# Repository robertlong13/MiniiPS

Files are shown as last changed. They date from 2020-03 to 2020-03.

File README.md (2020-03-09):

# MiniiPS
Custom regulator board for miniaturized Wii. Provides 1V, 1.15V, 3.3V, 5V. Similar to the PowerMiiLite, but larger and a few extra features specific to my personal project. Should be good for any wall-powered mini Wii project.

### Goals for this power supply
* Be small. Can't really afford much more space than 20mm by 60mm
* Use a 5V 3A USB-C charger for input power
* Have an enable pin for turning on and off the power supply. The slide switch I'm using for power is only rated for 200mA.
* Design the 3.3V, 1.15V, and 1V regulators for 3A output, and 15V input voltage. I'm over-engineering to give myself maximum chance of getting it right on the first try, instead of pushing all my components right to their spec. There could be some reason I this is a bad idea, but I can't think of one.
* Be easy to hand assemble (using skillet reflow) and rework. An automated assembly run is out of the question. Smallest passives are 0603 (1608 metric).

To power on the outputs, the enable pad must be pulled high with your power switch. By default, that pad is pulled low with a 10K resistor.

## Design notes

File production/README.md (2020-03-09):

# Production
This folder contains all necessary for manufacturing

|File Name| Description  |
|--|--|
| BOM.csv | Bill of Materials, CSV |
| BOM.xlsx | Bill of Materials, Excel |
| ComponentPlacement.pdf | Reference for Hand Assembly |
| MiniiPS-B_Cu.gbr | Bottom Copper |
| MiniiPS-B_Mask.gbr | Bottom Soldermask |
| MiniiPS-B_Paste.gbr | Bottom Solderpaste |
| MiniiPS-B_SilkS.gbr | Bottom Silkscreen |
| MiniiPS-Edge_Cuts.gbr | Board Outline |
| MiniiPS-F_Cu.gbr | Top Copper |
| MiniiPS-F_Mask.gbr | Top Soldermask |
| MiniiPS-F_Paste.gbr | Top Solderpaste |
| MiniiPS-F_SilkS.gbr | Top Silkscreen |
| MiniiPS-PTH.drl | Plated Holes |

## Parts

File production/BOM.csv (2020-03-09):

Reference(s) | Value | MFG Name | MFG Part Num | Description | Qty
C1, C2, C8, C9, C15, C16 | 10u | Taiyo Yuden | TMK212BBJ106KG-T | CAP CER 10UF 25V X5R 0805 | 6
C3, C4, C10, C11, C17, C18, C23, C24 | 100n | Samsung Electro-Mechanics | CL10B104KB8NNNC | CAP CER 0.1UF 50V X7R 0603 | 8
C5, C6, C7, C12, C13, C14, C19, C20, C21, C22, C25 | 22u | Samsung Electro-Mechanics | CL21A226MQQNNNE | CAP CER 22UF 6.3V X5R 0805 | 11
J1 |  | GCT | USB4085-GF-A | CONN RCPT USB2.0 TYPEC 16POS | 1
L1, L2, L3 | 2u2 | Murata Electronics | 1264EY-2R2N=P3 | FIXED IND 2.2UH 7.8A 19.2 MOHM | 3
R1 | 3K16 | Stackpole Electronics Inc | RMCF0603FT3K16 | RES 3.16K OHM 1% 1/10W 0603 | 1
R2, R4, R6, R7, R8 | 10K | Stackpole Electronics Inc | RMCF0603FT10K0 | RES 10K OHM 1% 1/10W 0603 | 5
R3, R9, R10 | 5K11 | Stackpole Electronics Inc | RMCF0603FT5K11 | RES 5.11K OHM 1% 1/10W 0603 | 3
R5 | 33K2 | Stackpole Electronics Inc | RMCF0603FT33K2 | RES 33.2K OHM 1% 1/10W 0603 | 1
U1, U2, U3 | TPS564201 | Texas Instruments | TPS564201DDCR | IC REG BUCK ADJ 4A TSOT23-6 | 3
U4 | AP2171 | Diodes Incorporated | AP2171WG-7 | IC PWR SWITCH P-CHAN 1:1 SOT25 | 1

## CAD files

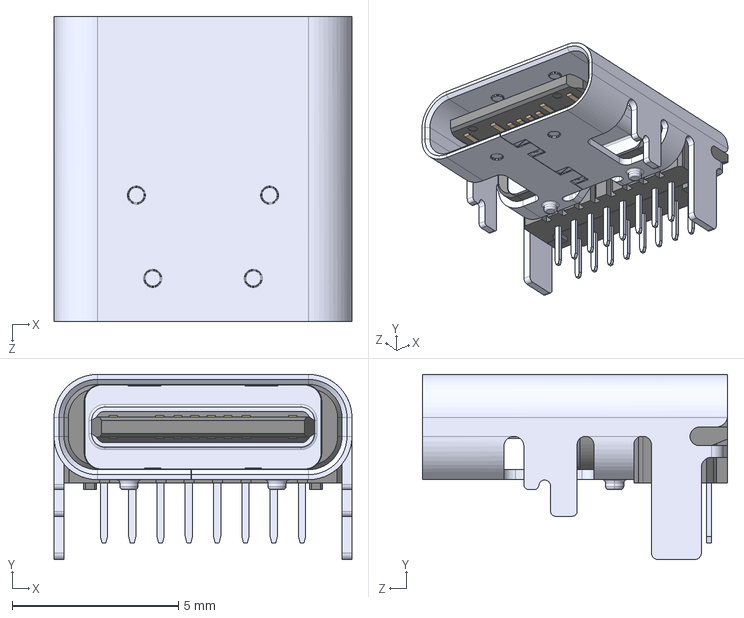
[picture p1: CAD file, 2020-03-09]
USB4085-GF-A--3DModel-STEP-56544.STEP
8.95 x 5.56 x 9.17 mm

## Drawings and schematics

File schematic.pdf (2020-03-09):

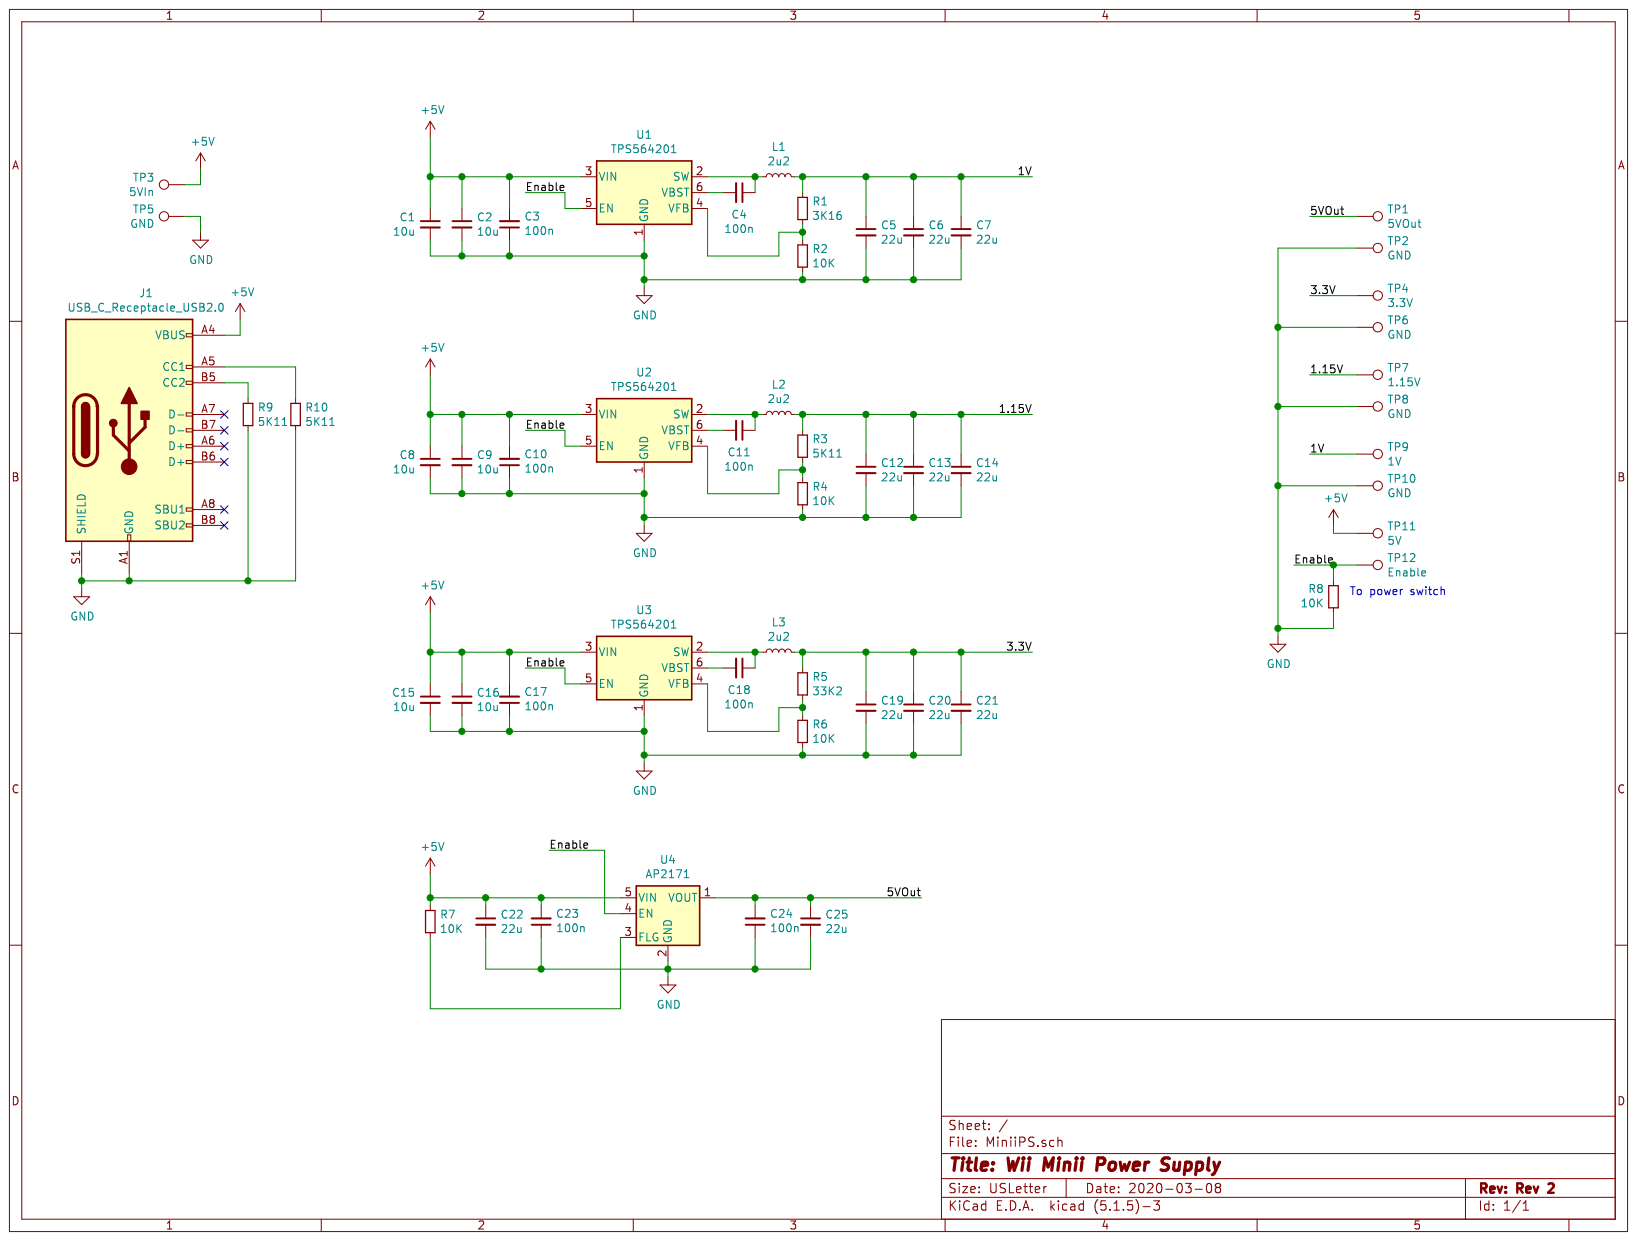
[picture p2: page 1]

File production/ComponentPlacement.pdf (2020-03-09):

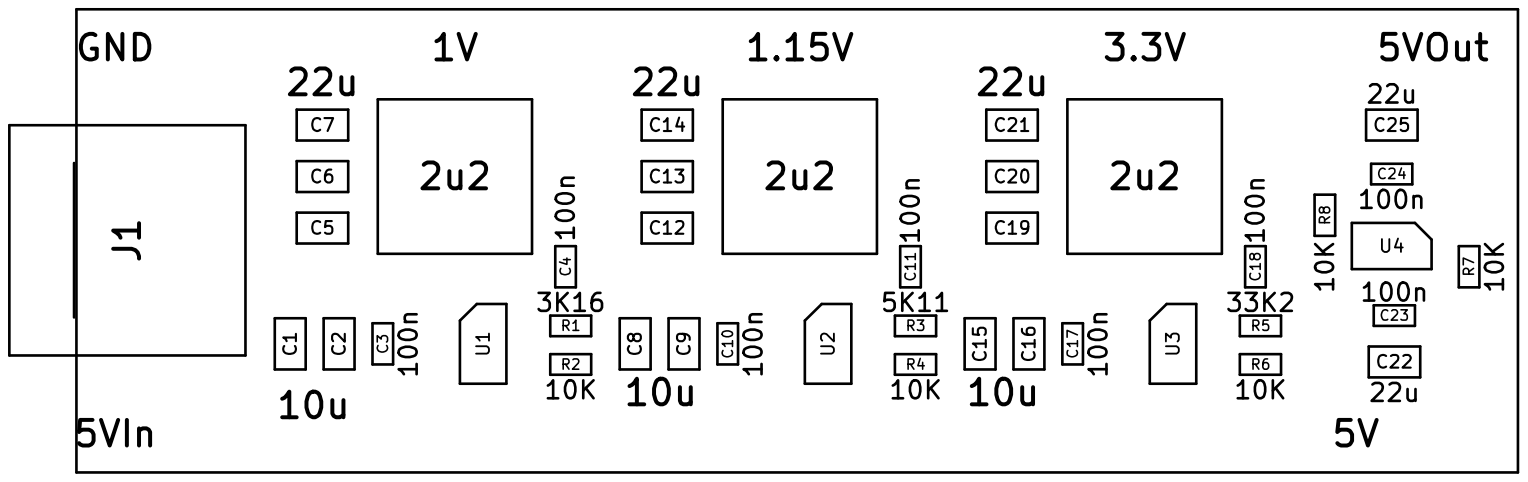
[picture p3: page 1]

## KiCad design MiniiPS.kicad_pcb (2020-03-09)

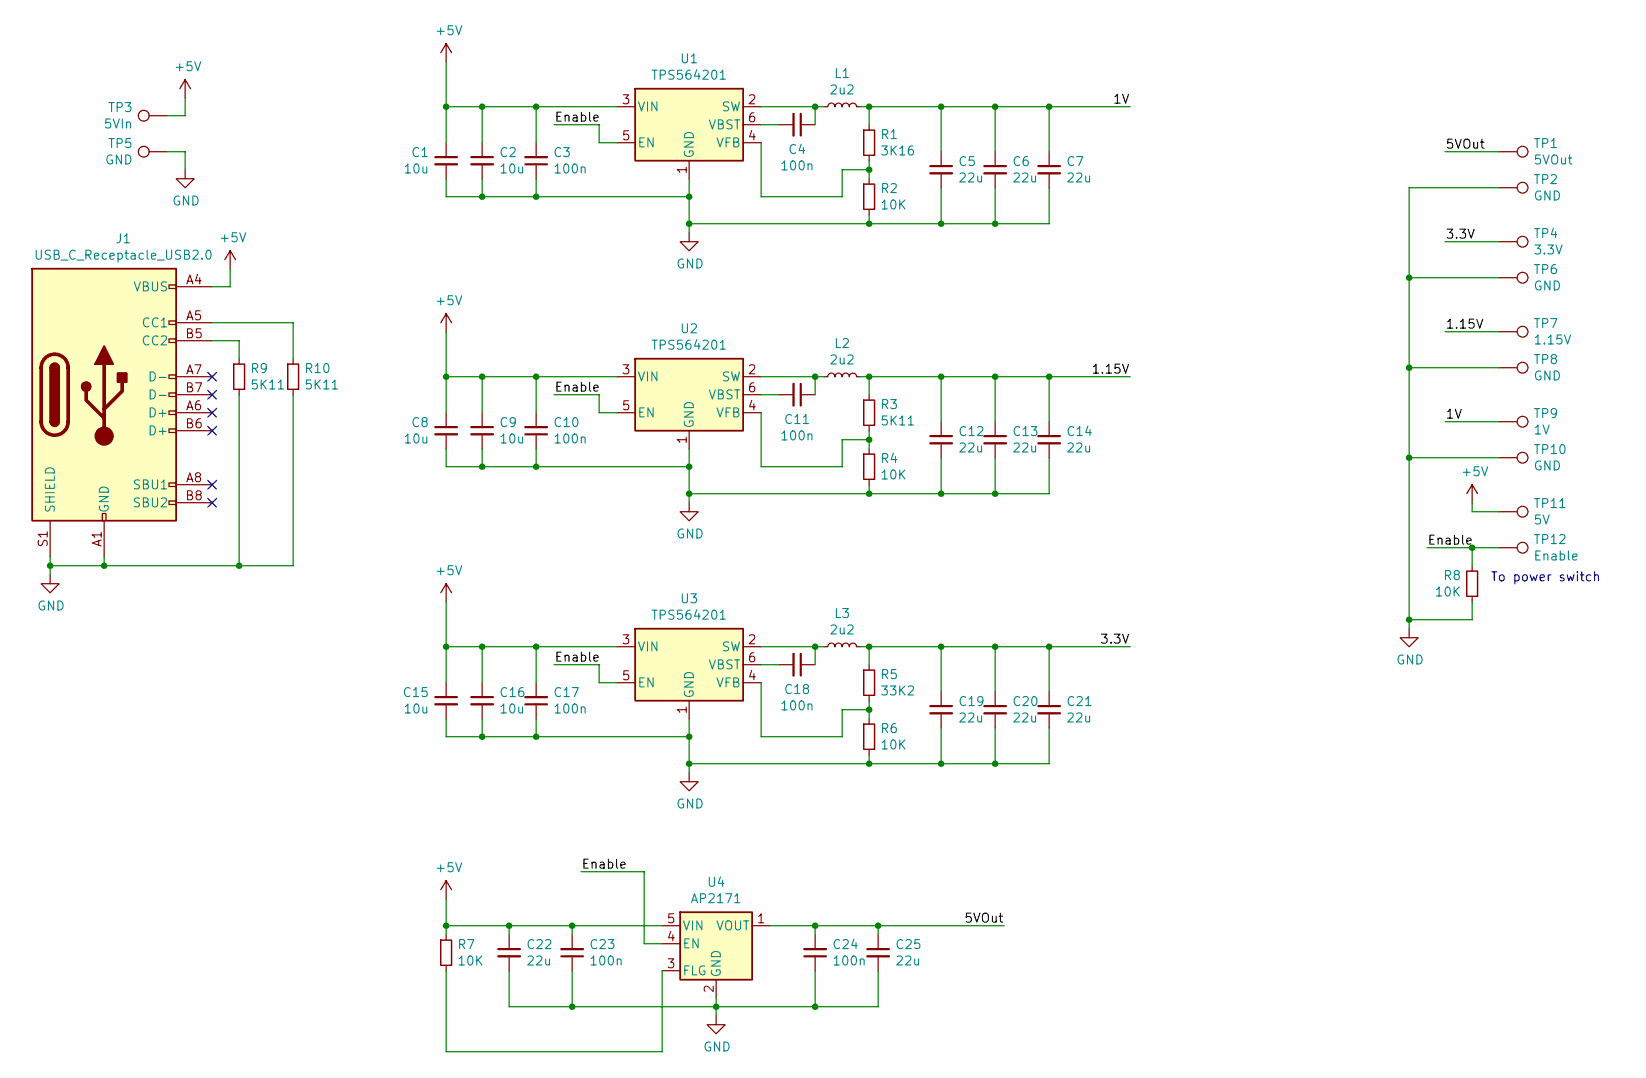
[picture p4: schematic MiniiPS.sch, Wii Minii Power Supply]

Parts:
C1, C2, C8, C9, C15, C16: 10u; C_0805_2012Metric; MFG Part Num TMK212BBJ106KG-T
C3, C4, C10, C11, C17, C18, C23, C24: 100n; C_0603_1608Metric; MFG Part Num CL10B104KB8NNNC
C5, C6, C7, C12, C13, C14, C19, C20, C21, C22, C25: 22u; C_0805_2012Metric; MFG Part Num CL21A226MQQNNNE
J1: USB_C_Receptacle_USB2.0; USB_C_Receptacle_GCT_USB4085; MFG Part Num USB4085-GF-A
L1, L2, L3: 2u2; MFG Part Num 1264EY-2R2N=P3
R1: 3K16; R_0603_1608Metric; MFG Part Num RMCF0603FT3K16
R2, R4, R6, R7, R8: 10K; R_0603_1608Metric; MFG Part Num RMCF0603FT10K0
R3, R9, R10: 5K11; R_0603_1608Metric; MFG Part Num RMCF0603FT5K11
R5: 33K2; R_0603_1608Metric; MFG Part Num RMCF0603FT33K2
TP1: 5VOut; TestPoint_Pad_4.0x4.0mm
TP2, TP5, TP6, TP8, TP10: GND; TestPoint_Pad_4.0x4.0mm
TP3: 5VIn; TestPoint_Pad_4.0x4.0mm
TP4: 3.3V; TestPoint_Pad_4.0x4.0mm
TP7: 1.15V; TestPoint_Pad_4.0x4.0mm
TP9: 1V; TestPoint_Pad_4.0x4.0mm
TP11: 5V; TestPoint_Pad_4.0x4.0mm
TP12: Enable; TestPoint_Pad_4.0x4.0mm
U1, U2, U3: TPS564201; SOT-23-6; MFG Part Num TPS564201DDCR
U4: AP2171; SOT-23-5; MFG Part Num AP2171WG-7

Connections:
+5V: C1.1, C2.1, C3.2, C8.1, C9.1, C10.2, C15.1, C16.1, C17.2, C22.1, C23.2, J1.A4 (VBUS), J1.A9 (VBUS), J1.B4 (VBUS), J1.B9 (VBUS), R7.1, TP3.1, TP11.1, U1.3 (VIN), U2.3 (VIN), U3.3 (VIN), U4.5 (VIN)
/1.15V: C12.1, C13.1, C14.1, L2.2, R3.1, TP7.1
/1V: C5.1, C6.1, C7.1, L1.2, R1.1, TP9.1
/3.3V: C19.1, C20.1, C21.1, L3.2, R5.1, TP4.1
/5VOut: C24.2, C25.1, TP1.1, U4.1 (VOUT)
/Enable: R8.2, TP12.1, U1.5 (EN), U2.5 (EN), U3.5 (EN), U4.4 (EN)
GND: C1.2, C2.2, C3.1, C5.2, C6.2, C7.2, C8.2, C9.2, C10.1, C12.2, C13.2, C14.2, C15.2, C16.2, C17.1, C19.2, C20.2, C21.2, C22.2, C23.1, C24.1, C25.2, J1.A1 (GND), J1.A12 (GND), J1.B1 (GND), J1.B12 (GND), J1.S1 (SHIELD), R2.2, R4.2, R6.2, R8.1, R9.2, R10.2, TP2.1, TP5.1, TP6.1, TP8.1, TP10.1, U1.1 (GND), U2.1 (GND), U3.1 (GND), U4.2 (GND)
unnamed: C4.1, L1.1, U1.2 (SW)
unnamed: C4.2, U1.6 (VBST)
unnamed: C11.1, L2.1, U2.2 (SW)
unnamed: C11.2, U2.6 (VBST)
unnamed: C18.1, L3.1, U3.2 (SW)
unnamed: C18.2, U3.6 (VBST)
unnamed: J1.A5 (CC1), R10.1
unnamed: J1.B5 (CC2), R9.1
unnamed: R1.2, R2.1, U1.4 (VFB)
unnamed: R3.2, R4.1, U2.4 (VFB)
unnamed: R5.2, R6.1, U3.4 (VFB)
unnamed: R7.2, U4.3 (FLG)

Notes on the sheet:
To power switch

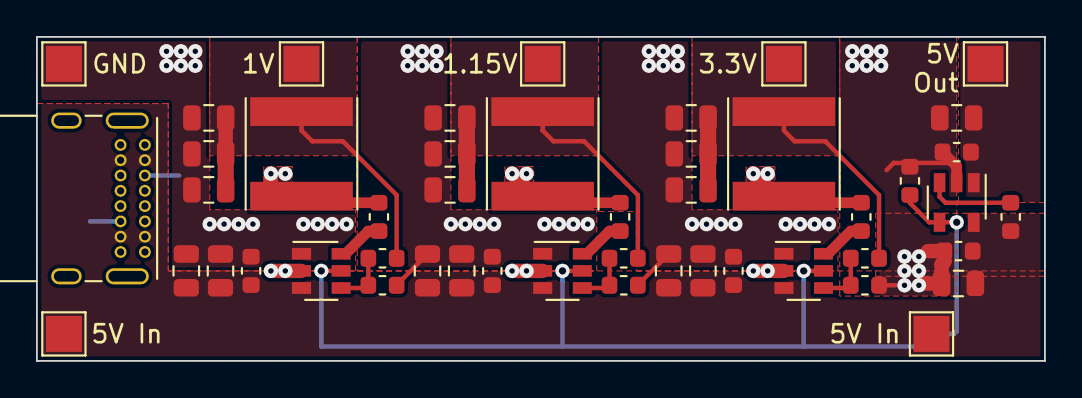
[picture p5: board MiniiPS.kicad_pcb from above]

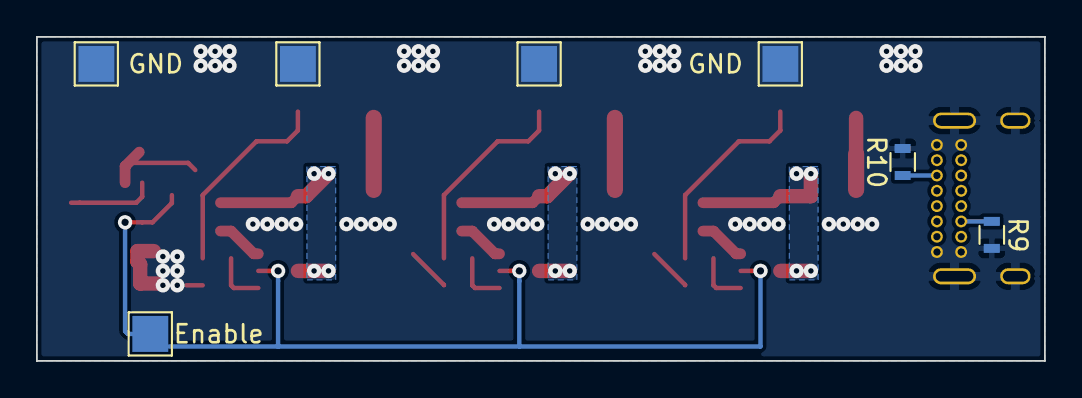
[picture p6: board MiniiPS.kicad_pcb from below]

Board: 2 copper layers, 56.0 x 18.0 mm, 55 parts (7 on the bottom side), 19 nets.
